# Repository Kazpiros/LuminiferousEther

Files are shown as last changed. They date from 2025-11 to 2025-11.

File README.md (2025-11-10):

# Wham!

## This is
>Taking me too long to finish
---
Specs: 
**RP2350**
- Has mac instructions
- Multithreadding
- pio
- 150 MHz
---

#TODO
- Fix ADC input 
  - My theory is R7 is loading down the Guitar. need 50-100k to fix this.
- RTOS
- PASSTHRU
- CONIDITIONING
- ORDER BRAIN
- DO EFFECTS
--- 

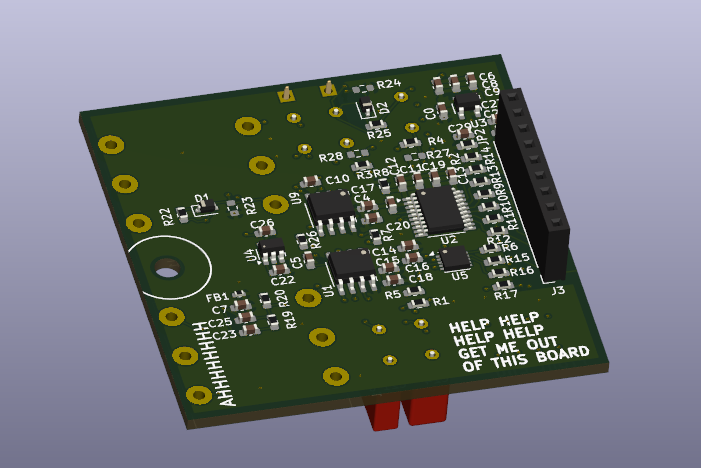
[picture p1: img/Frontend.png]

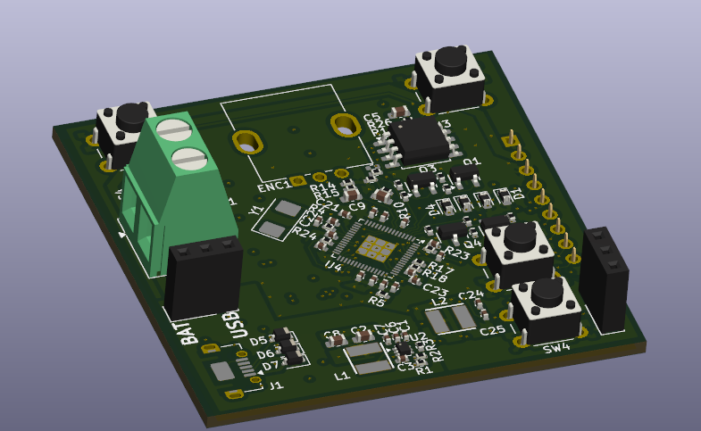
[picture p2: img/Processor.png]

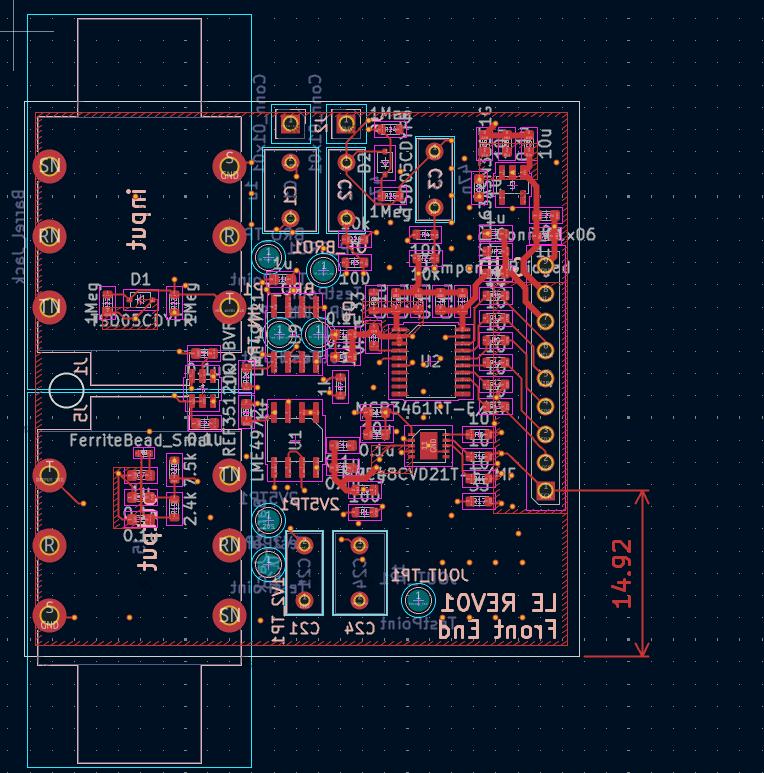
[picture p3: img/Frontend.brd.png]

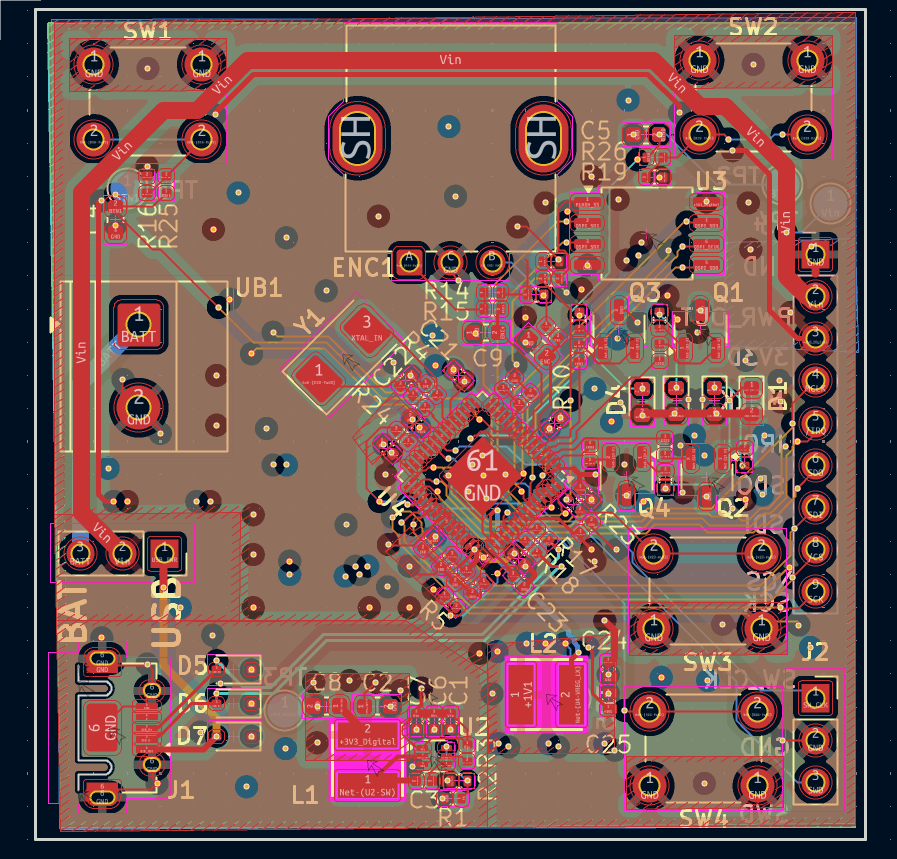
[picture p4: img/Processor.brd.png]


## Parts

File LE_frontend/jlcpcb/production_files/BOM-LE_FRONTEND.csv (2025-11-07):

Comment | Designator | Footprint | LCSC | Quantity
0.1u | C11,C12,C13,C15,C16,C17,C18,C19,C20,C22,C23,C25,C26,C4,C8 | C_0603_1608Metric | C14663 | 15
1u | C0,C10,C28,C29,C5,C7 | C_0603_1608Metric | C15849 | 6
Jumper_2_Bridged | JP2 | R_0603_1608Metric | C21189 | 1
100 | R1,R26,R3,R4,R7 | R_0603_1608Metric | C22775 | 5
10 | R10,R11,R12,R13,R14,R15,R16,R6,R9 | R_0603_1608Metric | C22859 | 9
1Meg | R22,R24,R25,R5 | R_0603_1608Metric | C22935 | 4
2.4k | R19 | R_0603_1608Metric | C22940 | 1
33 | R17,R2,R8 | R_0603_1608Metric | C23140 | 3
7.5k | R20 | R_0603_1608Metric | C23234 | 1
10k | R28 | R_0603_1608Metric | C25197 | 1
10u | C14,C27,C6,C9 | C_0603_1608Metric | C96446 | 4
FerriteBead_Small | FB1 | R_0402_1005Metric |  | 1
TSD05CDYFR | D1 | D_SOD-323 |  | 1
TSD05CDYFR | D2 | D_SOD-323 |  | 1
LME49721 | U9 | SOIC-8_3.9x4.9mm_P1.27mm |  | 1
MCP3461RT-E/ST | U2 | TSSOP-20_4.4x6.5mm_P0.65mm |  | 1
MCP48CVD21T-E/MF | U5 | DFN-10-1EP_3x3mm_P0.5mm_EP1.55x2.48mm |  | 1
Conn_01x06 | J3 | PinSocket_1x09_P2.54mm_Vertical |  | 1
NCP163ASN330T1G | U3 | SOT-23-5 |  | 1
REF35120QDBVR | U4 | SOT-23-6 |  | 1
LME49721 | U1 | SOIC-8_3.9x4.9mm_P1.27mm |  | 1
47n | C2 | C_Rect_L7.2mm_W3.0mm_P5.00mm_FKS2_FKP2_MKS2_MKP2 |  | 1
Barrel_Jack | J5 | Jack_6.35mm_Neutrik_NMJ6HFD2_Horizontal |  | 1
TestPoint | JIN_TP1 | TestPoint_Pad_D2.0mm |  | 1
0.1u | C21 | C_Rect_L7.2mm_W3.0mm_P5.00mm_FKS2_FKP2_MKS2_MKP2 |  | 1
1u | C24 | C_Rect_L7.2mm_W4.5mm_P5.00mm_FKS2_FKP2_MKS2_MKP2 |  | 1
Barrel_Jack | J1 | Jack_6.35mm_Neutrik_NMJ6HFD2_Horizontal |  | 1
TestPoint | 1V2_TP1 | TestPoint_Pad_D2.0mm |  | 1
TestPoint | OP_BRO1 | TestPoint_Pad_D2.0mm |  | 1
TestPoint | JOUT_TP1 | TestPoint_Pad_D2.0mm |  | 1
TestPoint | 2V5TP1 | TestPoint_Pad_D2.0mm |  | 1
1u | C1 | C_Rect_L7.2mm_W4.5mm_P5.00mm_FKS2_FKP2_MKS2_MKP2 |  | 1
TestPoint | BRO_TP1 | TestPoint_Pad_D2.0mm |  | 1
Conn_01x01 | J2 | PinSocket_1x01_P2.54mm_Vertical |  | 1
47n | C3 | C_Rect_L7.2mm_W3.0mm_P5.00mm_FKS2_FKP2_MKS2_MKP2 |  | 1
Conn_01x01 | J6 | PinSocket_1x01_P2.54mm_Vertical |  | 1
TestPoint | OP_JIN1 | TestPoint_Pad_D2.0mm |  | 1

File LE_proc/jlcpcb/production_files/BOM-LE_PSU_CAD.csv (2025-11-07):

Comment | Designator | Footprint | LCSC | Quantity
1k | R12,R13,R23,R24,R4,R6,R8 | R_0402_1005Metric | C11702 | 7
0.1u | C1,C11,C12,C13,C14,C15,C16,C17,C18,C19,C20,C26,C27,C3 | C_0402_1005Metric | C1525 | 14
15p | C21,C22 | C_0402_1005Metric | C1548 | 2
10u | C6,C7 | C_0402_1005Metric | C15525 | 2
ABM8-272-T3 | Y1 | Crystal_SMD_Abracon_ABM3-2Pin_5.0x3.2mm | C20625731 | 1
LED | D1,D2,D3,D4 | D_0603_1608Metric | C2286 | 4
4.7u | C23,C24,C25,C28 | C_0402_1005Metric | C23733 | 4
27 | R17,R18 | R_0402_1005Metric | C25092 | 2
10k | R1,R14,R16,R19,R25,R26,R28,R3 | R_0402_1005Metric | C25744 | 8
10 | R10,R11,R15,R27,R7,R9 | R_0402_1005Metric | C25905 | 6
30.9k | R2,R5 | R_0402_1005Metric | C270615 | 2
RP2350A-QFN60 | U4 | QFN-60-1EP_7x7mm_P0.4mm_EP3.4x3.4mm | C42411118 | 1
22u | C2,C8 | C_0603_1608Metric | C59461 | 2
NMOS | Q1,Q2,Q3,Q4 | SOT-23-3 | C8545 | 4
10uF | C10,C4,C5,C9 | C_0603_1608Metric | C96446 | 4
BOOT_SEL | SW3 | SW_PUSH_6mm_H5mm |  | 1
W25Q128JVS | U3 | SOIC-8_5.3x5.3mm_P1.27mm |  | 1
D_TVS | D6 | D_SOD-323 |  | 1
SW_Push | SW1 | SW_PUSH_6mm_H5mm |  | 1
3.3uH | L1 | WE-LQS_4025 |  | 1
Battery | UB1 | TerminalBlock_Phoenix_MKDS-1,5-2_1x02_P5.00mm_Horizontal |  | 1
USB_B_Micro | J1 | USB_Micro-AB_Molex_47590-0001 |  | 1
RUN_SW | SW4 | SW_PUSH_6mm_H5mm |  | 1
SW_Push | SW2 | SW_PUSH_6mm_H5mm |  | 1
0R | R22 | R_0402_1005Metric |  | 1
D_TVS | D7 | D_SOD-323 |  | 1
TPS562202 | U2 | SOT-563 |  | 1
Conn_01x03 | J2 | PinSocket_1x03_P2.54mm_Vertical |  | 1
D_TVS | D5 | D_SOD-323 |  | 1
3.3uH | L2 | WE-LQS_4025 |  | 1
TestPoint | TP1 | TestPoint_Pad_D2.0mm |  | 1
TestPoint | TP2 | TestPoint_Pad_D2.0mm |  | 1
Conn_01x09 | J3 | PinSocket_1x09_P2.54mm_Vertical |  | 1
TestPoint | TP3 | TestPoint_Pad_D2.0mm |  | 1
TestPoint | TP4 | TestPoint_Pad_D2.0mm |  | 1
TestPoint | TP5 | TestPoint_Pad_D2.0mm |  | 1
RotaryEncoder | ENC1 | RotaryEncoder_Bourns_Vertical_PEC12R-3x17F-Nxxxx |  | 1
Conn_01x03 | BATT_USB_JMP1 | PinSocket_1x03_P2.54mm_Vertical |  | 1

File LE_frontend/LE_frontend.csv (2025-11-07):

Reference | Qty | Value | DNP | Exclude from BOM | Exclude from Board | Footprint | Datasheet
1V2_TP1,2V5TP1,BRO_TP1,JIN_TP1,JOUT_TP1,OP_BRO1,OP_JIN1 | 7 | TestPoint |  |  |  | TestPoint:TestPoint_Pad_D2.0mm | ~
C1,C24 | 2 | 1u |  |  |  | Capacitor_THT:C_Rect_L7.2mm_W4.5mm_P5.00mm_FKS2_FKP2_MKS2_MKP2 | ~
C2,C3 | 2 | 47n |  |  |  | Capacitor_THT:C_Rect_L7.2mm_W3.0mm_P5.00mm_FKS2_FKP2_MKS2_MKP2 | ~
C21 | 1 | 0.1u |  |  |  | Capacitor_THT:C_Rect_L7.2mm_W3.0mm_P5.00mm_FKS2_FKP2_MKS2_MKP2 | ~
D1,D2 | 2 | TSD05CDYFR |  |  |  | Diode_SMD:D_SOD-323 | ~
FB1 | 1 | FerriteBead_Small |  |  |  | Resistor_SMD:R_0402_1005Metric | ~
J2,J6 | 2 | Conn_01x01 |  |  |  | Connector_PinSocket_2.54mm:PinSocket_1x01_P2.54mm_Vertical | ~
J3 | 1 | Conn_01x06 |  |  |  | Connector_PinSocket_2.54mm:PinSocket_1x08_P2.54mm_Vertical | ~
J4 | 1 | Conn_01x02 |  |  |  | Connector_PinSocket_2.54mm:PinSocket_1x02_P2.54mm_Vertical | ~
U1,U9 | 2 | LME49721 |  |  |  | Package_SO:SOIC-8_3.9x4.9mm_P1.27mm | https://www.ti.com/lit/ds/symlink/tlv9062.pdf
U2 | 1 | MCP3461RT-E/ST |  |  |  | Package_SO:TSSOP-20_4.4x6.5mm_P0.65mm | MCP3461RT-E/ST
U3 | 1 | NCP163ASN330T1G |  |  |  | Package_TO_SOT_SMD:SOT-23-5 | https://www.onsemi.com/pdf/datasheet/ncp163-d.pdf
U4 | 1 | REF35120QDBVR |  |  |  | Package_TO_SOT_SMD:SOT-23-6 | https://www.ti.com/lit/ds/symlink/ref35.pdf
U5 | 1 | MCP48CVD21T-E/MF |  |  |  | Package_DFN_QFN:DFN-10-1EP_3x3mm_P0.5mm_EP1.55x2.48mm | MCP48CVD21T-E/MF

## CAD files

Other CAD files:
LE_proc/74404043033A/WE-LQS_4025.step

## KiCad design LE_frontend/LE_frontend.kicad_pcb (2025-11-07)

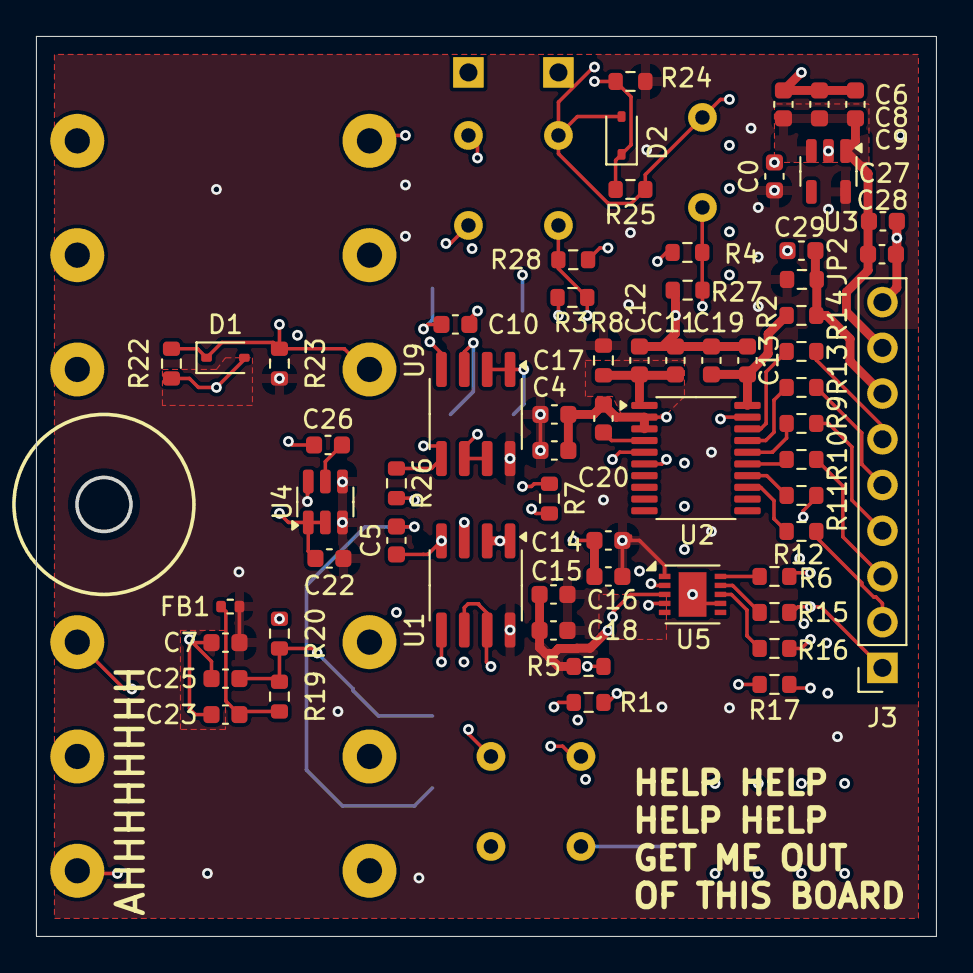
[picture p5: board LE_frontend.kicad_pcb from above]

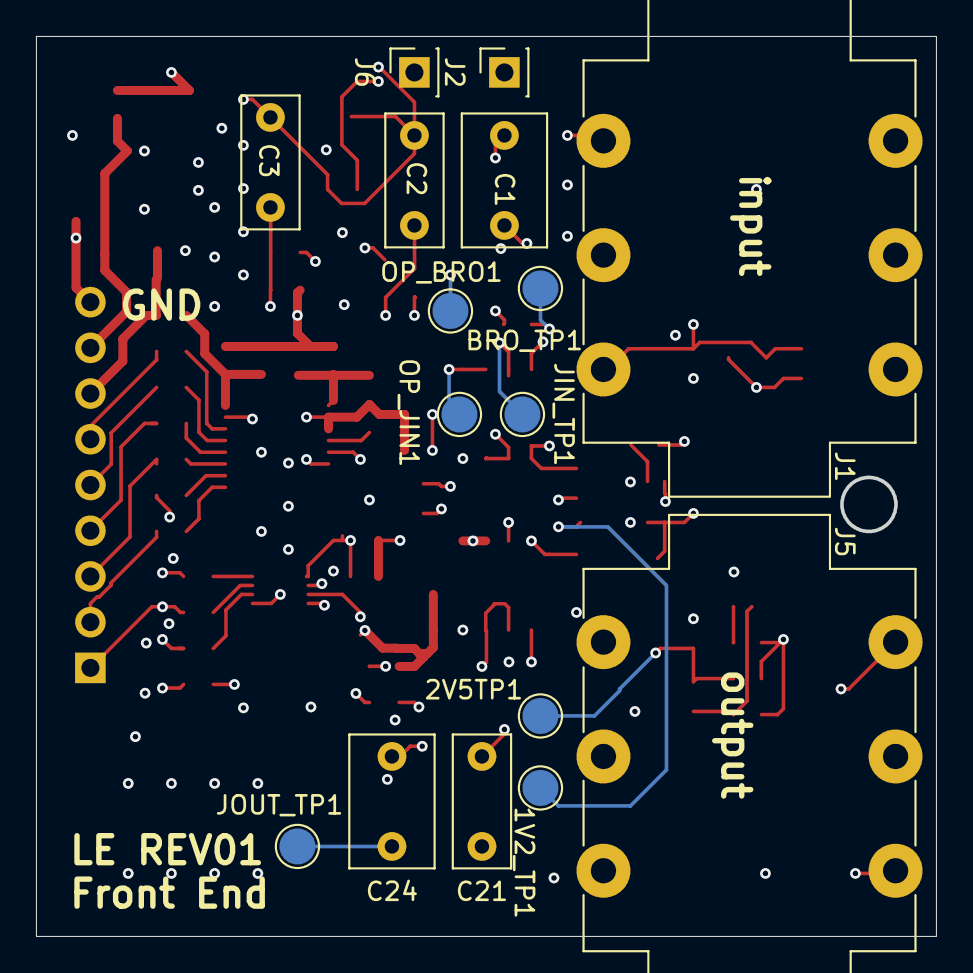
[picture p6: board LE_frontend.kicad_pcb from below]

Board: 6 copper layers, 50.0 x 50.0 mm, 78 parts (16 on the bottom side), 40 nets.

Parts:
1V2_TP1, 2V5TP1: TestPoint; TestPoint_Pad_D2.0mm
BRO_TP1: TestPoint; TestPoint_Pad_D2.0mm
C0, C5, C7, C10, C28, C29: 1u; C_0603_1608Metric
C1, C24: 1u; C_Rect_L7.2mm_W4.5mm_P5.00mm_FKS2_FKP2_MKS2_MKP2
C2, C3: 47n; C_Rect_L7.2mm_W3.0mm_P5.00mm_FKS2_FKP2_MKS2_MKP2
C4, C8, C11, C12, C13, C15, C16, C17, C18, C19, C20, C22, C23, C25, C26: 0.1u; C_0603_1608Metric
C6, C9, C14, C27: 10u; C_0603_1608Metric
C21: 0.1u; C_Rect_L7.2mm_W3.0mm_P5.00mm_FKS2_FKP2_MKS2_MKP2
D1, D2: TSD05CDYFR; D_SOD-323
FB1: FerriteBead_Small; R_0402_1005Metric
J1, J5: Barrel_Jack; Jack_6.35mm_Neutrik_NMJ6HFD2_Horizontal
J2, J6: Conn_01x01; PinSocket_1x01_P2.54mm_Vertical
J3: Conn_01x06; PinSocket_1x09_P2.54mm_Vertical
JIN_TP1: TestPoint; TestPoint_Pad_D2.0mm
JOUT_TP1: TestPoint; TestPoint_Pad_D2.0mm
JP2: Jumper_2_Bridged; R_0603_1608Metric
OP_BRO1: TestPoint; TestPoint_Pad_D2.0mm
OP_JIN1: TestPoint; TestPoint_Pad_D2.0mm
R1, R3, R4: 100; R_0603_1608Metric
R2, R8, R17: 33; R_0603_1608Metric
R5, R22, R23, R24, R25: 1Meg; R_0603_1608Metric
R6, R9, R10, R11, R12, R13, R14, R15, R16: 10; R_0603_1608Metric
R7, R26: 1k; R_0603_1608Metric
R19: 2.4k; R_0603_1608Metric
R20: 7.5k; R_0603_1608Metric
R27, R28: 10k; R_0603_1608Metric
U1, U9: LME49721; SOIC-8_3.9x4.9mm_P1.27mm
U2: MCP3461RT-E/ST; TSSOP-20_4.4x6.5mm_P0.65mm
U3: NCP163ASN330T1G; SOT-23-5
U4: REF35120QDBVR; SOT-23-6
U5: MCP48CVD21T-E/MF; DFN-10-1EP_3x3mm_P0.5mm_EP1.55x2.48mm

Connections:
+3V3_Analog: C0.1, C4.2, C7.2, C14.2, C15.2, C16.2, C17.2, C18.2, C22.2, FB1.1, JP2.1 (A), R8.1, R23.1, R24.1, U1.8 (V+), U3.5 (VOUT), U4.3 (EN), U4.4 (VIN), U5.1 (VDD), U9.8 (V+)
+3V3_DIG: C29.1, J3.7, JP2.2 (B), R2.2
/1V2: R7.2, R26.2, U1.1, U1.2 (-)
/2V5: 2V5TP1.1, C25.2, R19.2, R20.1, U5.3 (VREF)
/2V5_INPUT_FILTER: C23.2, FB1.2, R19.1
/ADC_PWR_AVDD: C11.2, C12.2, R8.2, U2.1 (AVDD)
/ADC_PWR_DVDD: C13.2, C19.2, R2.1, U2.20 (DVDD)
/IN+: C2.2, R3.2, R28.2, U2.5 (CH0)
/IN-: C3.2, R4.2, R27.2, U2.6 (CH1)
/MCLK: J3.6, R14.1
/Neg_input_Header: C10.1, D2.1 (A1), J2.1, R24.2, R25.1
/OUTPUT_SIG: C24.2, J5.T, JOUT_TP1.1, R5.1
/POS_INPUT_SIG: C1.1, D1.1 (A1), J1.T, R22.1, R23.2
/SCK: J3.1, R11.1, R15.1
/SDI: J3.3, R6.1, R10.1
/SDO: J3.4, R9.1, R16.1
/U1_INPUT_SIG: C21.2, R1.2, U1.5 (+)
/U1_OUTPUT_SIG: C24.1, U1.6 (-), U1.7
/U1_REFERENCE_NON-INVERTING: 1V2_TP1.1, C5.2, U1.3 (+), U4.6 (VREF)
/U9_input_neg: BRO_TP1.1, C10.2, R26.1, U9.5 (+)
/U9_output_neg: OP_BRO1.1, R4.1, U9.6 (-), U9.7
/U9_output_pos: OP_JIN1.1, R3.1, U9.1, U9.2 (-)
/VOUT: R1.1, U5.4 (VOUT)
//CS: J3.2, R12.1, R17.1
//IRQ: J3.5, R13.1
GND: C0.2, C2.1, C3.1, C4.1, C5.1, C6.2, C7.1, C8.2, C9.2, C11.1, C12.1, C13.1, C14.1, C15.1, C16.1, C17.1, C18.1, C19.1, C20.1, C21.1, C22.1, C23.1, C25.1, C26.1, C27.2, C28.2, C29.2, D1.2 (A2), D2.2 (A2), J1.S, J3.9, J5.S, J6.1, R5.2, R20.2, R22.2, R25.2, R27.1, R28.1, U1.4 (V-), U2.2 (AGND), U2.3 (REFIN-), U2.19 (DGND), U3.2 (GND), U4.1 (GND), U4.2 (GND), U5.7 (VSS), U5.11 (VSS), U9.4 (V-)
unnamed: R12.2, U2.13 (*CS)
unnamed: R13.2, U2.17 (*IRQ/MDAT)
unnamed: R14.2, U2.18 (MCLK)
unnamed: C20.2, U2.4 (REFIN+/OUT)
unnamed: R11.2, U2.14 (SCK)
unnamed: R10.2, U2.15 (SDI)
unnamed: R9.2, U2.16 (SDO)
unnamed: C26.2, U4.5 (NR)
unnamed: R17.2, U5.2 (*CS)
unnamed: R15.2, U5.9 (SCK)
unnamed: R6.2, U5.10 (SDI)
unnamed: R16.2, U5.8 (SDO)
unnamed: C1.2, JIN_TP1.1, R7.1, U9.3 (+)
Vin: C6.1, C8.1, C9.1, C27.1, C28.1, J3.8, U3.1 (VIN), U3.3 (EN)

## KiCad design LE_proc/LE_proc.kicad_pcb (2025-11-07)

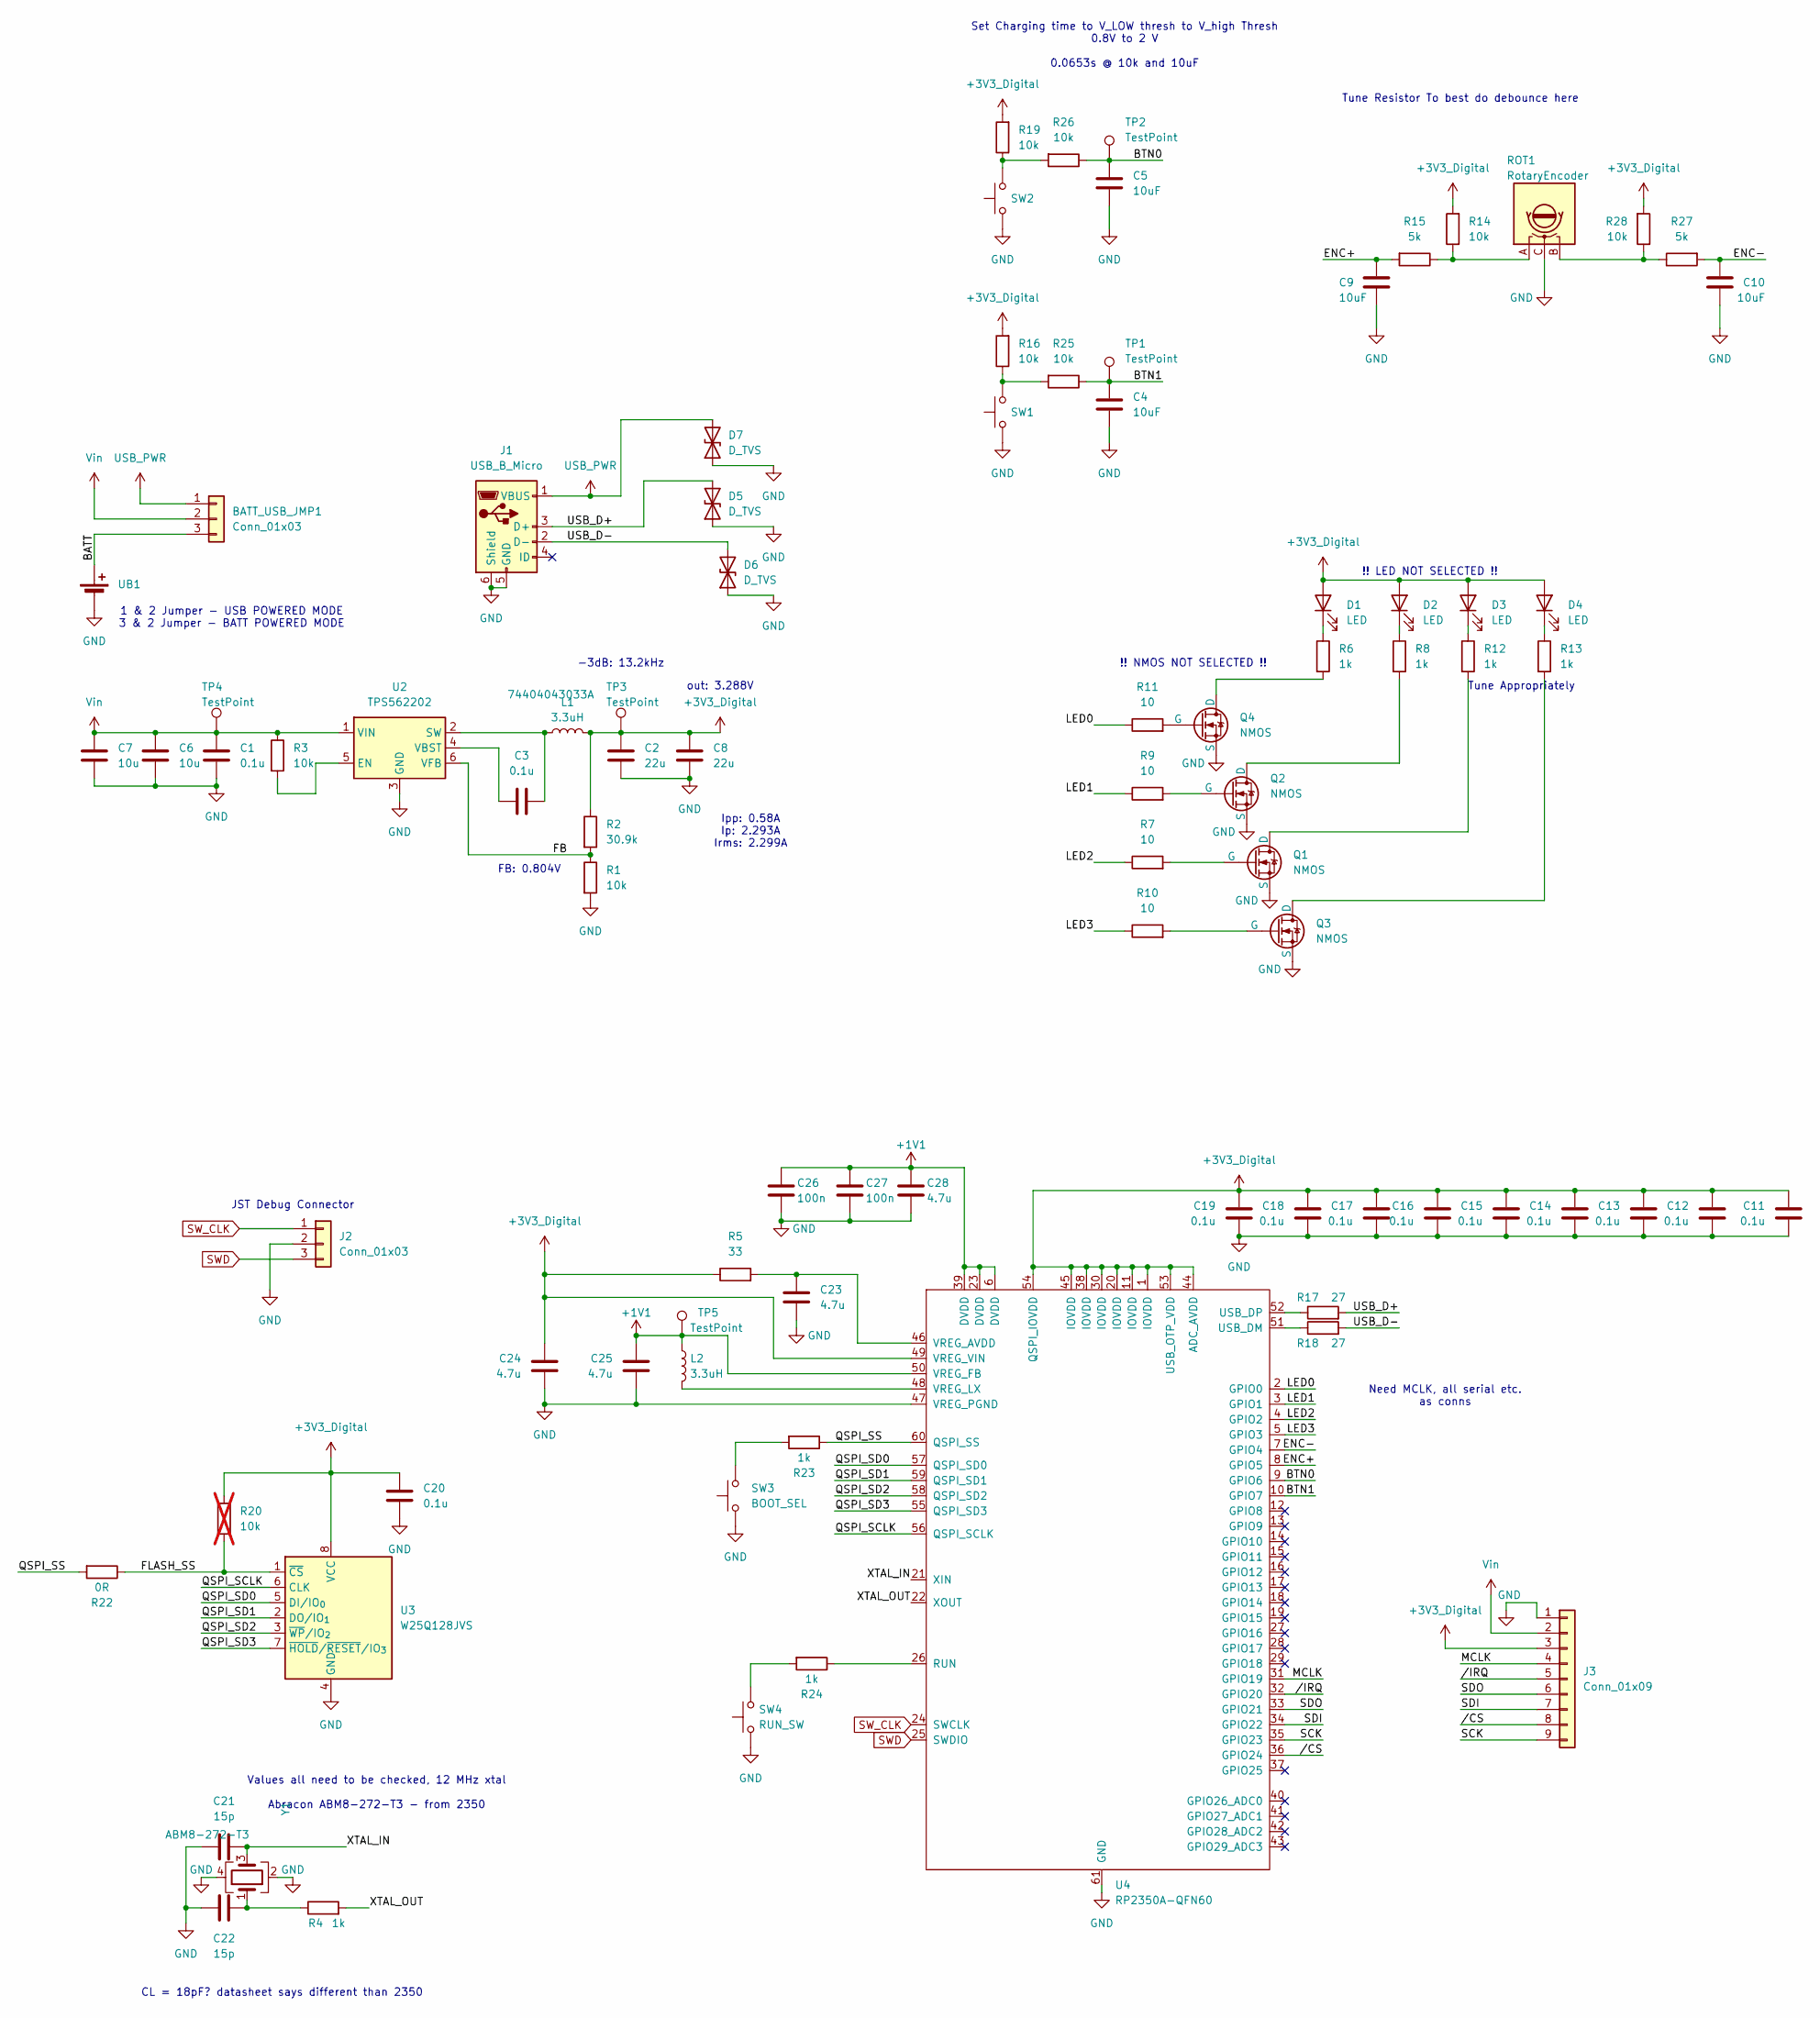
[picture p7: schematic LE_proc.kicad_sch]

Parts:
BATT_USB_JMP1: Conn_01x03; PinSocket_1x03_P2.54mm_Vertical
C1, C3, C11, C12, C13, C14, C15, C16, C17, C18, C19, C20: 0.1u; C_0402_1005Metric
C2, C8: 22u; C_0603_1608Metric
C4, C5, C9, C10: 10uF; C_0603_1608Metric
C6, C7: 10u; C_0402_1005Metric
C21, C22: 15p; C_0402_1005Metric
C23, C24, C25, C28: 4.7u; C_0402_1005Metric
C26, C27: 100n; C_0402_1005Metric
D1, D2, D3, D4: LED; D_0603_1608Metric
D5, D6, D7: D_TVS; D_SOD-323
J1: USB_B_Micro; USB_Micro-AB_Molex_47590-0001
J2: Conn_01x03; PinSocket_1x03_P2.54mm_Vertical
J3: Conn_01x09; PinSocket_1x09_P2.54mm_Vertical
L1, L2: 3.3uH; WE-LQS_4025
Q1, Q2, Q3, Q4: NMOS; SOT-23-3
R1, R3, R14, R16, R19, R25, R26, R28: 10k; R_0402_1005Metric
R2: 30.9k; R_0402_1005Metric
R4, R6, R8, R12, R13, R23, R24: 1k; R_0402_1005Metric
R5: 33; R_0402_1005Metric
R7, R9, R10, R11: 10; R_0402_1005Metric
R15, R27: 5k; R_0402_1005Metric
R17, R18: 27; R_0402_1005Metric
R20: 10k; R_0402_1005Metric; not fitted
R22: 0R; R_0402_1005Metric
ROT1: RotaryEncoder; RotaryEncoder_Bourns_Vertical_PEC12R-3x17F-Nxxxx
SW1, SW2: SW_Push; SW_PUSH_6mm_H5mm
SW3: BOOT_SEL; SW_PUSH_6mm_H5mm
SW4: RUN_SW; SW_PUSH_6mm_H5mm
TP1, TP2, TP3, TP4, TP5: TestPoint; TestPoint_Pad_D2.0mm
U2: TPS562202; SOT-563
U3: W25Q128JVS; SOIC-8_5.3x5.3mm_P1.27mm
U4: RP2350A-QFN60; QFN-60-1EP_7x7mm_P0.4mm_EP3.4x3.4mm
UB1: Battery; TerminalBlock_Phoenix_MKDS-1,5-2_1x02_P5.00mm_Horizontal
Y1: ABM8-272-T3; Crystal_SMD_Abracon_ABM3-2Pin_5.0x3.2mm

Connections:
+1V1: C25.1, C26.1, C27.1, C28.1, L2.1, TP5.1, U4.6 (DVDD), U4.23 (DVDD), U4.39 (DVDD), U4.50 (VREG_FB)
+3V3_Digital: C2.1, C8.1, C11.1, C12.1, C13.1, C14.1, C15.1, C16.1, C17.1, C18.1, C19.1, C20.1, C24.1, D1.2 (A), D2.2 (A), D3.2 (A), D4.2 (A), J3.3, L1.2, R2.1, R5.1, R14.2, R16.2, R19.2, R20.2, R28.2, TP3.1, U3.8 (VCC), U4.1 (IOVDD), U4.11 (IOVDD), U4.20 (IOVDD), U4.30 (IOVDD), U4.38 (IOVDD), U4.44 (ADC_AVDD), U4.45 (IOVDD), U4.49 (VREG_VIN), U4.53 (USB_OTP_VDD), U4.54 (QSPI_IOVDD)
/BATT: BATT_USB_JMP1.3, UB1.1 (+)
/BTN0: C5.2, R26.1, TP2.1, U4.9 (GPIO6)
/BTN1: C4.2, R25.1, TP1.1, U4.10 (GPIO7)
/ENC+: C9.2, R15.2, U4.8 (GPIO5)
/ENC-: C10.2, R27.2, U4.7 (GPIO4)
/FB: R1.1, R2.2, U2.6 (VFB)
/FLASH_SS: R20.1, R22.1, U3.1 (~CS)
/LED0: R11.1, U4.2 (GPIO0)
/LED1: R9.1, U4.3 (GPIO1)
/LED2: R7.1, U4.4 (GPIO2)
/LED3: R10.1, U4.5 (GPIO3)
/MCLK: J3.4, U4.31 (GPIO19)
/QSPI_SCLK: U3.6 (CLK), U4.56 (QSPI_SCLK)
/QSPI_SD0: U3.5 (DI/IO_{0}), U4.57 (QSPI_SD0)
/QSPI_SD1: U3.2 (DO/IO_{1}), U4.59 (QSPI_SD1)
/QSPI_SD2: U3.3 (~WP/IO_{2}), U4.58 (QSPI_SD2)
/QSPI_SD3: U3.7 (~HOLD/~RESET/IO_{3}), U4.55 (QSPI_SD3)
/QSPI_SS: R22.2, R23.1, U4.60 (QSPI_SS)
/SCK: J3.9, U4.35 (GPIO23)
/SDI: J3.7, U4.34 (GPIO22)
/SDO: J3.6, U4.33 (GPIO21)
/USB_D+: D5.2 (A2), J1.3 (D+), R17.2
/USB_D-: D6.2 (A2), J1.2 (D-), R18.2
/XTAL_IN: C21.2, U4.21 (XIN), Y1.3
/XTAL_OUT: R4.2, U4.22 (XOUT)
//CS: J3.8, U4.36 (GPIO24)
//IRQ: J3.5, U4.32 (GPIO20)
GND: C1.2, C2.2, C4.1, C5.1, C6.2, C7.2, C8.2, C9.1, C10.1, C11.2, C12.2, C13.2, C14.2, C15.2, C16.2, C17.2, C18.2, C19.2, C20.2, C21.1, C22.1, C23.2, C24.2, C25.2, C26.2, C27.2, C28.2, D5.1 (A1), D6.1 (A1), D7.1 (A1), J1.5 (GND), J1.6 (Shield), J2.2, J3.1, Q1.3 (S), Q2.3 (S), Q3.3 (S), Q4.3 (S), R1.2, ROT1.C, SW1.1, SW2.1, SW3.1, SW4.1, U2.3 (GND), U3.4 (GND), U4.47 (VREG_PGND), U4.61 (GND), UB1.2 (-), Y1.2, Y1.4; also elsewhere on the board
unnamed: C22.2, R4.1, Y1.1
unnamed: D1.1 (K), R6.1
unnamed: D2.1 (K), R8.1
unnamed: D3.1 (K), R12.1
unnamed: D4.1 (K), R13.1
unnamed: Q1.1 (D), R12.2
unnamed: Q1.2 (G), R7.2
unnamed: Q2.1 (D), R8.2
unnamed: Q2.2 (G), R9.2
unnamed: Q3.1 (D), R13.2
unnamed: Q3.2 (G), R10.2
unnamed: Q4.1 (D), R6.2
unnamed: Q4.2 (G), R11.2
unnamed 43: R14.1, R15.1, ROT1.A; also elsewhere on the board
unnamed: R16.1, R25.2, SW1.2
unnamed: R19.1, R26.2, SW2.2
unnamed: R23.2, SW3.2
unnamed: R24.2, SW4.2
unnamed 48: R27.1, R28.1, ROT1.B; also elsewhere on the board
unnamed: R3.2, U2.5 (EN)
unnamed: C3.2, L1.1, U2.2 (SW)
unnamed: C3.1, U2.4 (VBST)
unnamed: R24.1, U4.26 (RUN)
unnamed: R18.1, U4.51 (USB_DM)
unnamed: R17.1, U4.52 (USB_DP)
unnamed: C23.1, R5.2, U4.46 (VREG_AVDD)
unnamed: L2.2, U4.48 (VREG_LX)
SWD: J2.3, U4.25 (SWDIO)
SW_CLK: J2.1, U4.24 (SWCLK)
USB_PWR: BATT_USB_JMP1.1, D7.2 (A2), J1.1 (VBUS)
Vin: BATT_USB_JMP1.2, C1.1, C6.1, C7.1, J3.2, R3.1, TP4.1, U2.1 (VIN)

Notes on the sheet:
!! NMOS NOT SELECTED !!
-3dB: 13.2kHz
Tune Appropriately
out: 3.288V
Set Charging time to V_LOW thresh to V_high Thresh 0.8V to 2 V 0.0653s @ 10k and 10uF
CL = 18pF? datasheet says different than 2350
Values all need to be checked, 12 MHz xtal Abracon ABM8-272-T3 - from 2350
FB: 0.804V
Ipp: 0.58A Ip: 2.293A Irms: 2.299A
1 & 2 Jumper - USB POWERED MODE 3 & 2 Jumper - BATT POWERED MODE
Tune Resistor To best do debounce here
JST Debug Connector
Need MCLK, all serial etc. as conns
!! LED NOT SELECTED !!

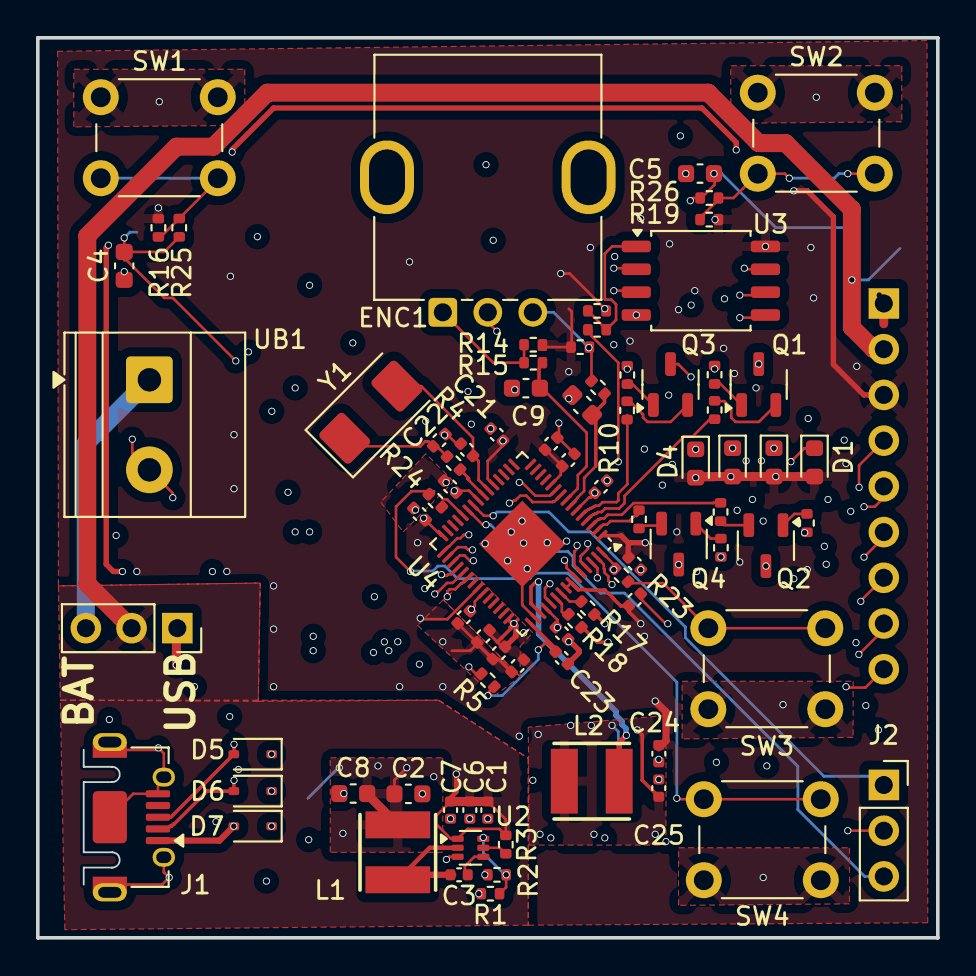
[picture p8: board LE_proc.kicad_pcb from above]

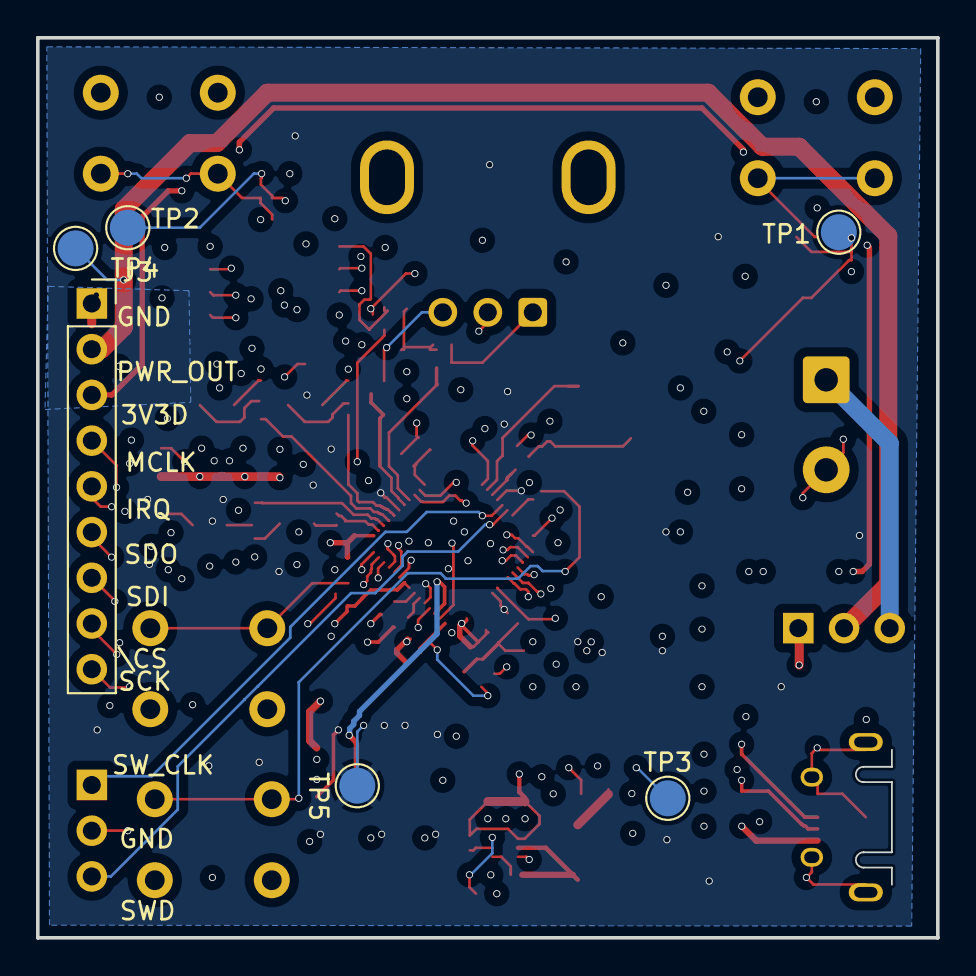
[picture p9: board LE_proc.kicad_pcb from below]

Board: 6 copper layers, 50.0 x 50.0 mm, 87 parts (6 on the bottom side), 61 nets.

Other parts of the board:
ENC1: RotaryEncoder; RotaryEncoder_Bourns_Vertical_PEC12R-3x17F-Nxxxx

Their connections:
GND: ENC1.C; also elsewhere on the board
unnamed 43: ENC1.A; also elsewhere on the board
unnamed 48: ENC1.B; also elsewhere on the board

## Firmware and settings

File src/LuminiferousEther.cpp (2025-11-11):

#include <cstdio>               // or <stdio.h>
#include <cstdint>

#include "include/le_defs.h"


//run with cmake --build build

/**
 * TODO:
 * - Need to add a #define for all CS pins so im not staring at "17"s
 * - Figure out memory leak in Ring buffer
 * - know that non-blocking reads will consume a bunch of processing time 90% is what it feels like.
 * - add a timer for exact sample rate.
 * - 
 * - Setup timer for output frequency control
 * - Make decimation filter to lower rate for DAC
 * - Delay effect + passthru + moving average 
 */

 /* summarizing:
  * Nov 10, 2025,
  * got DMA working, had information be able to be sent to pio to output pin given a "launch command"
  * this has an interrupt request as well. it may work. unsure.
  */

  /* IDEA
  * could have 2 spi functions: static single write, continuous?
  */
const char src[] = "Hello, world! (from DMA)";
char dst[count_of(src)];
// Get a free channel, panic() if there are none
int dma_chan = dma_claim_unused_channel(true);



void dma_handler()
{
    static bool first_run = true;
    if (first_run) {
        first_run = false;
    }
    // Clear the interrupt request.
    dma_hw->ints0 = 1u << dma_chan;
    int word[] = {0b01000001};
    dma_channel_set_read_addr(dma_chan, word, true);
}
int irq_flag = 0;

uint8_t rxbuf[4];
uint8_t txbuf[4] = {0b01000001,0,0,0};;
uint8_t zeros[4] = {0,0,0,0};

void gpio_irq_handler(uint gpio, uint32_t events) { //The GPIO callback function to handle interrupts
    uint32_t sample = (rxbuf[0] << 24) | (rxbuf[1] << 16) | (rxbuf[2] << 8) | rxbuf[3];
    irq_flag = 1;
}

int main()
{

    /** DMA is simple! just needs the TX and RX buffers. Probably good to have two channels. 
     * one for transmit, one for recieve.
     **/
    /***** DMA START *****/ 
    dma_channel_config c = dma_channel_get_default_config(dma_chan);
    channel_config_set_transfer_data_size(&c, DMA_SIZE_8);
    channel_config_set_read_increment(&c, true);
    channel_config_set_write_increment(&c, true);
    dma_channel_configure(
        dma_chan,          // Channel to be configured
        &c,            // The configuration we just created
        &pio0_hw->txf[0],// The initial write address. Write address (only need to set this once)
        NULL,// The initial read address, not providing it yet
        count_of(src),          // Number of transfers; 
        false           // Start until named.
    );
    //dma_channel_wait_for_finish_blocking(dma_chan); // freezes till its done, this is optional.


    /***** DMA END *****/

    /********pio start********/
    PIO pio = pio0;
    dma_channel_set_irq0_enabled(dma_chan, true);

    /* attempt at sharing  line 140 in reference (uart dma)*/
    //irq_add_shared_handler(pio_get_irq_num(pio, 0), pio_irq_handler, PICO_SHARED_IRQ_HANDLER_DEFAULT_ORDER_PRIORITY);
    //pio_set_irqn_source_enabled(pio, 0, pio_get_rx_fifo_not_empty_interrupt_source(pio_sm_rx), true);
    //irq_set_enabled(pio_get_irq_num(pio, 0), true);
    /* attempt at sharing */

    irq_set_exclusive_handler(DMA_IRQ_0, dma_handler);
    irq_set_enabled(DMA_IRQ_0, true);
    dma_handler(); // manually call it to start the transfers & pio program.

    stdio_init_all();

    gpio_init(PIN_IRQ);
    gpio_set_dir(PIN_IRQ, GPIO_IN);
    gpio_pull_down(PIN_IRQ);
    

    int temp = 0;

    dac_config_set();

    gpio_init(PIN_CS);
    gpio_put(PIN_CS, 1);
    gpio_set_dir(PIN_CS, GPIO_OUT);
    pio_spi_inst_t spi = {
            .pio = pio0,
            .sm = 0,
            .cs_pin = PIN_CS
    };
    uint offset = pio_add_program(spi.pio, &spi_cpha1_cs_program);
    printf("Loaded program at %d\n", offset);
    pio_spi_init(spi.pio, spi.sm, offset,
                 8,       // 8 bits per SPI frame
                 31.25f,  // 1 MHz @ 125 clk_sys
                 false,   // CPHA = 0
                 false,   // CPOL = 0
                 PIN_SCK,
                 PIN_MOSI,
                 PIN_MISO
    );
    bi_decl(bi_4pins_with_names(PICO_DEFAULT_SPI_RX_PIN, "SPI RX", PICO_DEFAULT_SPI_TX_PIN, "SPI TX", PICO_DEFAULT_SPI_SCK_PIN, "SPI SCK", PICO_DEFAULT_SPI_CSN_PIN, "SPI CS"));

    //adc_config_set();
    pio_adc_config_set(&spi, spi.cs_pin);
    while(1) // lil test batch
    {
        gpio_put(spi.cs_pin, 0);
        pio_spi_write8_read8_blocking(&spi, txbuf, rxbuf, 1);  //for static read 0b01000001
        gpio_put(spi.cs_pin, 1);
    }

    //sleep_us(10);
    //CONV_START(MUX_VINP_CH0);
    //sleep_us(10);

    while (1) {
        tight_loop_contents();
        
        gpio_put(spi.cs_pin, 0);
        pio_spi_write8_read8_blocking(&spi, txbuf, rxbuf, 1);  //for static read 0b01000001
        gpio_put(spi.cs_pin, 1);

        uint32_t sample = (rxbuf[0] << 24) | (rxbuf[1] << 16) | (rxbuf[2] << 8) | rxbuf[3];
        dma_handler();
        sleep_us(10);    
    }
}

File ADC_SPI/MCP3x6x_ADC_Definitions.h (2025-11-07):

/*******************************************************************************
* Company:
*   Microchip Technology Inc.
*
* File Name:
*   MCP3x6x_ADC_Definitions.h
*
* Summary:
*   MCP3x6x(R) Delta-Sigma ADC Configuration Bit setting definitions and Configuration 
*   Register initialization and Conversion-Start function prototypes. 
*
* Description:
*   This file contains the function prototypes for the MCP3x6x(R) Delta-Sigma ADC 
*   Configuration Register initialization and Conversion-Start functions for use 
*   with the Arduino Zero Board and the ATSAMD21G18 MCU.  
********************************************************************************/

/*******************************************************************************
* Copyright (C) 2023 Microchip Technology Inc. and its subsidiaries.
*
* Subject to your compliance with these terms, you may use Microchip software
* and any derivatives exclusively with Microchip products. It is your
* responsibility to comply with third party license terms applicable to your
* use of third party software (including open source software) that may
* accompany Microchip software.
*
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
* IN NO EVENT WILL MICROCHIP BE LIABLE FOR ANY INDIRECT, SPECIAL, PUNITIVE,
* INCIDENTAL OR CONSEQUENTIAL LOSS, DAMAGE, COST OR EXPENSE OF ANY KIND
* WHATSOEVER RELATED TO THE SOFTWARE, HOWEVER CAUSED, EVEN IF MICROCHIP HAS
* BEEN ADVISED OF THE POSSIBILITY OR THE DAMAGES ARE FORESEEABLE. TO THE
* FULLEST EXTENT ALLOWED BY LAW, MICROCHIP'S TOTAL LIABILITY ON ALL CLAIMS IN
* ANY WAY RELATED TO THIS SOFTWARE WILL NOT EXCEED THE AMOUNT OF FEES, IF ANY,
* THAT YOU HAVE PAID DIRECTLY TO MICROCHIP FOR THIS SOFTWARE.
************************************************************************************************************************************************************/

/***********************************************************************************************************************************************************/
/***********************************************************************************************************************************************************/
/*                                                  Section: MCP3x6x(R) Register Definitions                                                               */
/***********************************************************************************************************************************************************/
/***********************************************************************************************************************************************************/
#ifndef MCP_ADC_DEF_H
#define MCP_ADC_DEF_H

/* ADCDATA REGISTER */
const uint8_t _ADCDATA_ = 0x00;               // ADCDATA Register Address.


/* CONFIG0 REGISTER */
const uint8_t _CONFIG0_ = 0x01;               // CONFIG0 Register Address.

    // CONFIG0_67 Settings
    #define CONFIG0_67_PSHTDN 0b11000000
    //#define CONFIG0_67_PSHTDN 0b10          
    //#define CONFIG0_67_PSHTDN 0b01          
    #define CONFIG0_67_FSHTDN 0b00000000

    // CLK_SEL Settings
    #define CLK_SEL_INTOSC_CLKOUT 0b00110000
    #define CLK_SEL_INTOSC_NOCLKOUT 0b00100000
    #define CLK_SEL_EXTCLK01 0b00010000
    #define CLK_SEL_EXTCLK00 0b00000000

    // CS_SEL Settings
    #define CS_SEL_150 0b00001100
    #define CS_SEL_37 0b00001000
    #define CS_SEL_09 0b00000100
    #define CS_SEL_NONE 0b00000000

    // ADC_MODE Settings
    #define ADC_MODE_CONV 0b00000011
    #define ADC_MODE_STDBY 0b00000010
    #define ADC_MODE_SHTDN01 0b00000001
    #define ADC_MODE_SHTDN00 0b00000000

    #define CONFIG0_CFG (CONFIG0_67_PSHTDN | CLK_SEL_INTOSC_NOCLKOUT | CS_SEL_NONE | ADC_MODE_STDBY)  /*0xE2*/


/* CONFIG1 REGISTER */
const uint8_t _CONFIG1_ = 0x02;               // CONFIG1 Register Address.

    // Pre-Scaler Settings
    #define PRE_MCLK8 0b11000000
    #define PRE_MCLK4 0b10000000
    #define PRE_MCLK2 0b01000000
    #define PRE_MCLK 0b00000000

    // OSR Settings
    #define OSR_98304 0b00111100
    #define OSR_81920 0b00111000
    #define OSR_49152 0b00110100
    #define OSR_40960 0b00110000
    #define OSR_24576 0b00101100
    #define OSR_20480 0b00101000
    #define OSR_16384 0b00100100
    #define OSR_8192 0b00100000
    #define OSR_4096 0b00011100
    #define OSR_2048 0b00011000
    #define OSR_1024 0b00010100
    #define OSR_512 0b00010000
    #define OSR_256 0b00001100
    #define OSR_128 0b00001000
    #define OSR_64 0b00000100
    #define OSR_32 0b00000000

    #define CONFIG1_CFG (PRE_MCLK | OSR_98304)  /*0x3C*/
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

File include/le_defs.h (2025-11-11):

#ifndef LE_DEFS_H
#define LE_DEFS_H

#define SAMPLE_RATE 22e3
#define OUTPUT_RATE 1e5 // idk if this is even right
#define DECIMATION_FACTOR () (static_cast<int>(SAMPLING_FREQUENCY / OUTPUT_FREQUENCY))

#include "pico/stdlib.h"
#include "hardware/spi.h"
#include "hardware/dma.h"
#include "hardware/pio.h"
#include "hardware/interp.h"
#include "hardware/timer.h"
#include "hardware/clocks.h"
#include "hardware/uart.h"
#include "pico/binary_info.h"

#include "ADC_SPI/MCP3x6x_Type_Definitions.h"                                                           // Variable definitions header-file.
#include "ADC_SPI/MCP3x6x_ADC_Definitions.h"                                                            // ADC definitions header-file.
#include "ADC_SPI/MCP3x6x_Peripheral_Definitions.h"                                                     // Peripheral definitions header-file.
#include "ADC_SPI/MCP3x6x_SPI_Definitions.h"

#include "include/NCO.hpp"
#include "include/cbuf.hpp"
#include "include/adc_spi_config.hpp"
#include "include/dac_spi_config.hpp"
#include "include/filter_coef.h"
#include "include/pio_spi.h"


#define SPI_PORT spi0 // all this will be removed soon
#define PIN_MISO 16
#define PIN_CS   17
#define PIN_SCK  18
#define PIN_MOSI 19
#define PIN_IRQ  20
#define PIN_MCLK 21

#define DAC0_WRITE_MASK 0x3FF

#endif

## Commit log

2025-11-07 added CAD files
    [ANALOG_PWR.kicad_sch, ANA_REF.kicad_sch, BOM-LE_FRONTEND.csv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]
2025-11-10 This works, irq, dma, and pio
2025-11-11 added pio. turns out dma was not needed.
